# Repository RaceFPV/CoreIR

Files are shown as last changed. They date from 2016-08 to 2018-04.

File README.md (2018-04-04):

**What is this?**

CoreIR is an ultra low cost IR timing gate transponder compatible with i-lap rc timing gates. Usually this type of timing system is used for RC car or drone racing to track how fast you can run laps around a track. Using cheap and easy to find hardware, we've seen builds as cheap as $3 per transponder!

*[Now with a detailed build guide!](http://mrickert.com/2016/10/12/building-your-own-coreir-transponder/)*

**What's inside?**

CoreIR comes ready for you to input any 7 digit transponder ID you'd like, just edit the main arduino file's tx_id (CoreIR.ino) to set which transponder ID you would like to have. We have tested with a range from 1111111 to 9999999, but please be aware some id numbers seem to read/perform better than others!

*Don't want to edit arduino files? Use the new [CoreIR-Uplink desktop app!](https://github.com/slacker87/CoreIR-Uplink)*

**Required parts:**
* Arduino pro mini or pro micro (pro micro preferred)
* 9.1 ohm resistor
* npn transistor (2N222 preferred)
* IR led (TSAL6400 preferred)
* Arduino IDE 1.8.3 or higher

**Testing:**

You should see the following once you have built your tranceiver to confirm the code/hardware is working properly...
* Once the firmware is flashed, the led on the arduino should blink two times per second
* If the arduino is blinking around 2x per second, then the code is running correctly
* If the arduino is not blinking, or is blinking seemingly at random, the code needs to be reflashed as the upload failed (or there's a hardware issue)
* With the arduino blinking, point your phone camera at the IR led, the led should be emitting a purple hue
* If you see the purple color from the led on your phone camera, congratulations! Everthing is running smoothly.
* If you do not see any purple hue, but the arduino is blinking steadily, there is a hardware wiring issue or the led has been damaged, check your wiring.

**Wiring:**

##### For micro and pro micro boards:

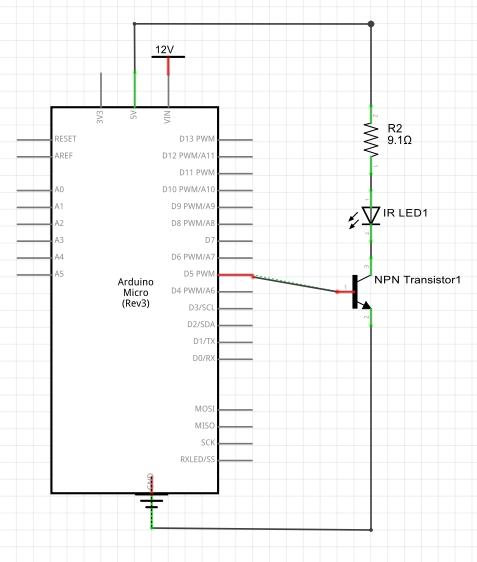
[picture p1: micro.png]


##### For nano and pro mini boards:

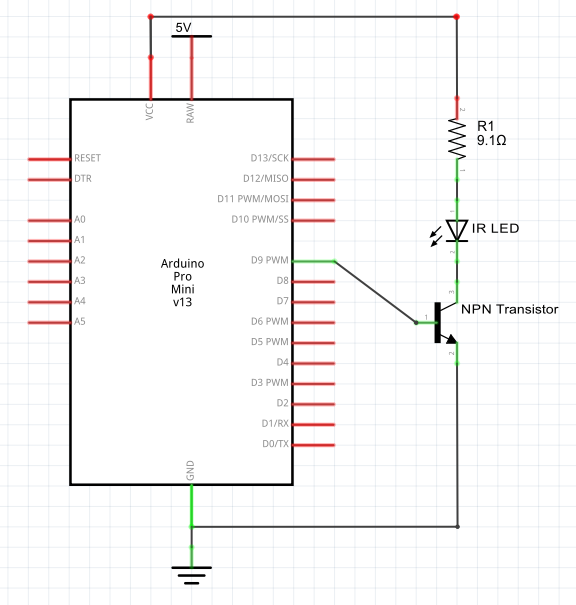
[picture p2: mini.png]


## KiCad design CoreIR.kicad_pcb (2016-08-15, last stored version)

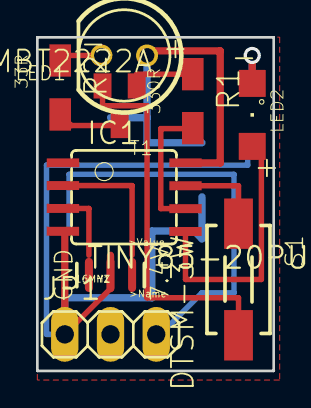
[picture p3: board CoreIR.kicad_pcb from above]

Board: 2 copper layers, 13.1 x 18.5 mm, 13 parts (0 on the bottom side), 12 nets.

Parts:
C1, C2: 10uF; C1206K
IC1: TINY85-20PU; 8S2
IC2: LD117AS50TR; SOT223
JP1: 1X03
LED1: LED5MM
LED2: SML1206
R1: 330R; R1206W
R2: 33R; R1206W
R3: 100R; R1206W
S1: DTSM-3W
T1: MMBT2222A; SOT23-BEC
Y1: 16MHZ; RESONATOR-SMD

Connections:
5V: C2.1, IC1.8, IC2.4, LED1.A
GND: C1.2, C2.2, IC1.4, IC2.1, JP1.1, R3.2, S1.2, T1.E, Y1.2
unnamed: IC1.5, LED2.A
unnamed: LED1.K, R2.1
unnamed: R2.2, T1.C
unnamed: R1.1, T1.B
unnamed: IC1.6, R1.2
unnamed: LED2.C, R3.1
unnamed: IC1.7, S1.1
unnamed: IC1.3, Y1.3
unnamed: IC1.2, Y1.1
VCC: C1.1, IC2.3, JP1.3

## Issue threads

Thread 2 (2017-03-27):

Undetected passes

EdwardDimaguila, 2017-03-27:
Hi Micheal,

I recently built this project transponder based on atmega 328. however i often missed laps especially when flying at high speeds through the sensor gate.

I read your commits and seen several times that you've changed the int khz value and finally settled to 426, why is it so? AFAIK the TSOP7000 IR detector used in the ilaps sensor bridge calls for 455khz as per datasheet, Gareth and Mitch measured the original ilaps transponders to have around 460 khz carrier, could this be the cause of my missed laps?

slacker87, 2017-06-19:
Potentially, but I've found that even stock ilap transponders have missed laps in certain conditions. Those conditions are: high speed flying, full sun directly on receiver gate. The sun emits a high enough amount of IR light that it effectively 'blinders' the receiver gate from properly seeing the transponders emitted IR led. Also please make sure your using version 2.0 as a _lot_ of improvements to readout were done for that build. One final note is that I used a logic analyzer to check the output of the IR pulses hitting the led from the arduino and it matches up 1 to 1 with the original boards. The original leds were picked so that ilap could dump direct uart out onto the led but with a bit of software magic that can be 'simulated' with software so that a different ir led can be used (as in this case). Hope this helps my apologies for the late response!

isopix, 2023-01-21:
I do wonder which is better and would skip less laps:
 - I-Lap (CoreIR)
 - Robitronic/EasyLap (RiCino Next)

Hi,

Could you comment on difference between I-Lap and Robitronic(and EasyLap clone)?
Both use IR and both got reverse-engineered clones.

https://github.com/zelogik/RicinoNext
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

They also have Robitronic compatible transponder:
https://github.com/zelogik/RicinoNext/tree/main/Hardware/Emitter/irda_robi
https://github.com/zelogik/RicinoNext/tree/main/Software

Isn't Robitronic better than I-Lap?

I know there's also reverse-engineered AMBrc clone (called RCHourGlass), but it's probably overkill for 1:43 cars

Closed 2017-06-19.

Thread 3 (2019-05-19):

Doesn't work with my i-lap rc timing gate

timemaster5, 2019-05-19:
Hi, sorry for the possibly stupid question. I tried everything to get this project working but without success. Here are some photos of my i-Lap gate system, can anybody confirm that is the same one as you're using with these transponders?

I tried multiple Arduinos - Pro Micro 3.3V 8Mhz (32u4), Pro Mini 5v 16Mhz (328p), both without any sign of readings (no blinking RX led on the receiver, no logged IDs). Also tried multiple IR diodes, your recommended one too. Transmission is working I can see the IDs sent with IR receiver build on a Raspberry Pi (irw tool).

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

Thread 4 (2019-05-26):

IR LED Pin

Orange-Murker, 2019-05-26:
IR output pin for ATmega328 (Arduino Pro Micro) should be 3 as the code states instead of 9 on the schematics. I tested PIN 3 and it outputs the signal.
```
// Arduino Duemilanove, Diecimila, LilyPad, Mini, Fio, Nano, etc
// ATmega48, ATmega88, ATmega168, ATmega328
#else
  //#define IR_USE_TIMER1   // tx = pin 9
  #define IR_USE_TIMER2     // tx = pin 3

#endif
```

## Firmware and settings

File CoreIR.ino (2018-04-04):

/*
*
* I-lap "transponder" compatible IR transmitter for RC timing system
*
* Type in a 7-digit ID and an alternate ID into the define fields before compiling.
* Note that using non-random ID numbers will increase your chances of encountering 
* another unit using the same ID.
* 
* !!!!IDs with repeated numbers may not register every pass. For best results don't repeat the same digit multiple times in a row!!!!
* Test ID code with system before using, if possible.
* 
*/
//CONFIGURABLE SECTION - SET TRANSPONDER ID
//Change transponder ID # by setting a different transponder number for tx_id
//WARNING: IDs set by CoreIR-Uplink tool will override these numbers
const long tx_id = 5118895;
const long tx_alt_id = 8901234;
const int easylap_id = 2;

// Enable debug info on serial output
//#define debug

// EasyRaceLapTimer support ---- TESTING
//  #define easytimer

//check which arduino board we are using and build accordingly
#if defined(__AVR_ATtiny84__) || defined(__AVR_ATtiny167__) || defined(__AVR_ATtiny85__)
  //if using an attiny build with all defaults, don't define anything
#elif defined(__AVR_ATmega32U4__)
  //if using an arduino micro build with eeprom enabled and different LED pin
  #define atmega
  #define micro
#elif defined(__AVR_ATmega328p__) || defined(__AVR_ATmega64__) || defined(__AVR_ATmega128__) || defined(__AVR_ATmega328__) || defined(__AVR_ATmega168__)
  //if using an atmega328p or similar build with eeprom enabled
  #define atmega
#else
  //define nothing
#endif

#ifdef easytimer
  #include "Easytimer.h"
#endif

//TODO, set pins for attiny85 boards
#ifdef micro
  // Set up alternate ID jumper bridge, shift pins because micro is special and uses pin 5 for IR output
  #define bridgePinIn 14
  #define bridgePinOut 15
  // Change the status LED location to the proper pin for the atmega32U4
  const int ledPin = 17;
#else
  // Set up alternate ID jumper bridge using normal pins 5 and 6
  #define bridgePinIn 5
  #define bridgePinOut 6
  // Use the normal status LED
  const int ledPin = 13;
#endif

// Include eeprom library for usb connectivity and CoreIR-Uplink ID saving
#ifdef atmega
  #include <EEPROM.h>
  #include "saved.h"
#endif
String incomingString = "";   // for incoming serial data

// Include libraries for IR LED frequency, speed and encoding
#include "IRsnd.h"
#include "Encode.h"

// Initialize IR LED send code
IRsend irsend;

// Set up status LED
int ledState = LOW;
long interval = 0;
unsigned long previousMillis = 0; // Allow status LED to blink without sacraficing a timer

void setup() {
  #ifdef atmega
    // save the new transponder numbers in eeprom if they are not already there
    if (EEPROMReadlong(64) != tx_id) {
      long tx_id = EEPROMReadlong(64);
    }
    if (EEPROMReadlong(70) != easylap_id) {
      long tx_alt_id = EEPROMReadlong(70);
    }
  #endif

  // set up jumper bridge for alternate ID
  pinMode(bridgePinIn, INPUT);
  digitalWrite(bridgePinIn, HIGH);
  pinMode(bridgePinOut, OUTPUT);
  digitalWrite(bridgePinOut, LOW);

  #ifdef atmega
    Serial.begin(9600);
    #if defined(micro) & defined(debug)
      while (!Serial)
    #endif
  #endif

  // Generate timecode
  #ifdef debug
    Serial.print("Building code from: ");
  #endif
  #if defined(easytimer)
    geteasylapcode();
  #else 
    if (digitalRead(bridgePinIn)) {
      #ifdef debug
        Serial.println("Main ID:");
        Serial.println(tx_id);
      #endif
      interval = 200; // Blink LED faster for regular id by default
      makeOutputCode(tx_id); // use alternate ID if unbridged
    } else {
      #ifdef debug
        Serial.println("Alternate ID: ");
        Serial.println(tx_alt_id);
      #endif
      interval = 1000; // Blink LED slower for alt id
      makeOutputCode(tx_alt_id); // use standard ID otherwise
    }
  #endif
  
  // Set up for blinking the status LED
  pinMode(ledPin, OUTPUT);
}

void loop() {
  #ifdef atmega
  //serial data stuff for coreir-uplink support
  // send data only when you receive data:
  #ifdef easytimer
    if (Serial.available() > 0) {
      // read the incoming byte:
      incomingString = Serial.readString();
      //if asked, send back the current ID
      if (incomingString == "readID") {
        Serial.println(EEPROMReadlong(70));
        incomingString = "";
      }
      else {
      //if asked, set a new ID
        incomingString.remove(0,7);
        long idtolong = incomingString.toInt();
        EEPROMWritelong(70, idtolong);
        delayMicroseconds(3000);
        long easylap_id = EEPROMReadlong(70);
        Serial.println(easylap_id);
        incomingString = "";
        }
      }
    #else
      if (Serial.available() > 0) {
      // read the incoming byte:
      incomingString = Serial.readString();
      //if asked, send back the current ID
      if (incomingString == "readID") {
        Serial.println(EEPROMReadlong(64));
        incomingString = "";
      }
      //if asked, set a new ID
      if (incomingString.length() > 7) {
        incomingString.remove(0,7);
        long idtolong = incomingString.toInt();
        EEPROMWritelong(64, idtolong);
        delayMicroseconds(3000);
        long tx_id = EEPROMReadlong(64);
        Serial.println(tx_id);
        incomingString = "";
        }
      }
    #endif
    #endif

    
  #ifdef easytimer
      irsend.sendRaw(buffer,NUM_BITS,38);
      delay(17 + random(0, 5));
   #else
      //Send the IR signal, then wait the appropriate amount of time before re-sending
      irsend.sendRaw(outputcode, codeLen, khz);
      delay(7 + random(2, 5));
    #endif
  
  // -----Status LED blink code start -----
    unsigned long currentMillis = millis();
    if (currentMillis - previousMillis >= interval) {
      // save the last time you blinked the LED
      previousMillis = currentMillis;
      // if the LED is off turn it on and vice-versa:
      if (ledState == LOW) {
        ledState = HIGH;
      } else {
        ledState = LOW;
      }
      // set the LED with the ledState of the variable:
      digitalWrite(ledPin, ledState);
    // -----LED blink code end -----
  }
  delayMicroseconds(500);
}

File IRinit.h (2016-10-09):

//******************************************************************************
// IRremote
// Origial code by Ken Shirriff
// Modified by Paul Stoffregen <paul@pjrc.com> to support other boards and timers
// Modified by Michael Rickert <Slacker87> for more accurate IR LED timings
// Interrupt code based on NECIRrcv by Joe Knapp
//******************************************************************************

#ifndef IRinit_h
#define IRinit_h

//------------------------------------------------------------------------------
// Include the right Arduino header
//
#if defined(ARDUINO) && (ARDUINO >= 100)
#  include <Arduino.h>
#else
# if !defined(IRPRONTO)
#   include <WProgram.h>
# endif
#endif

//------------------------------------------------------------------------------
// This handles definition and access to global variables
//
#ifdef IR_GLOBAL
# define EXTERN
#else
# define EXTERN extern
#endif

//------------------------------------------------------------------------------
// Information for the Interrupt Service Routine
//
#define RAWBUF  101  // Maximum length of raw duration buffer

typedef
  struct {
    // The fields are ordered to reduce memory over caused by struct-padding
    uint8_t       rcvstate;        // State Machine state
    uint8_t       blinkpin;
    uint8_t       blinkflag;       // true -> enable blinking of pin on IR processing
    uint8_t       rawlen;          // counter of entries in rawbuf
    unsigned int  timer;           // State timer, counts 50uS ticks.
    unsigned int  rawbuf[RAWBUF];  // raw data
    uint8_t       overflow;        // Raw buffer overflow occurred
  }
irparams_t;

// ISR State-Machine : Receiver States
#define STATE_IDLE      2
#define STATE_MARK      3
#define STATE_SPACE     4
#define STATE_STOP      5
#define STATE_OVERFLOW  6

// Allow all parts of the code access to the ISR data
// NB. The data can be changed by the ISR at any time, even mid-function
// Therefore we declare it as "volatile" to stop the compiler/CPU caching it
EXTERN  volatile irparams_t  irparams;

//------------------------------------------------------------------------------
// Defines for blinking the LED
//

#if defined(CORE_LED0_PIN)
  # define BLINKLED        CORE_LED0_PIN
  # define BLINKLED_ON()   (digitalWrite(CORE_LED0_PIN, HIGH))
  # define BLINKLED_OFF()  (digitalWrite(CORE_LED0_PIN, LOW))
#else
  # define BLINKLED        13
  # define BLINKLED_ON()  (PORTB |= B00100000)
  # define BLINKLED_OFF()  (PORTB &= B11011111)
#endif

//------------------------------------------------------------------------------
// CPU Frequency
//
// microseconds per clock interrupt tick
# define USECPERTICK 50

#ifdef F_CPU
  # define SYSCLOCK  F_CPU     // main Arduino clock
#else
  # define SYSCLOCK  16000000  // main Arduino clock
#endif

//------------------------------------------------------------------------------
// Defines for setting and clearing register bits
//
#ifndef cbi
  # define cbi(sfr, bit)  (_SFR_BYTE(sfr) &= ~_BV(bit))
#endif

#ifndef sbi
  # define sbi(sfr, bit)  (_SFR_BYTE(sfr) |= _BV(bit))
#endif

//------------------------------------------------------------------------------
// Define which timer to use
//

// Micro and Pro micro - ATmega32U4
#if defined(__AVR_ATmega32U4__)
  //#define IR_USE_TIMER1   // tx = pin 14
  #define IR_USE_TIMER3   // tx = pin 9

//MegaCore - ATmega64, ATmega128
#elif defined(__AVR_ATmega64__) || defined(__AVR_ATmega128__)
  #define IR_USE_TIMER1     // tx = pin 13

// MightyCore - ATmega8535, ATmega16, ATmega32
#elif defined(__AVR_ATmega8535__) || defined(__AVR_ATmega16__) || defined(__AVR_ATmega32__)
  #define IR_USE_TIMER1     // tx = pin 13

// Atmega8
#elif defined(__AVR_ATmega8__)
  #define IR_USE_TIMER1     // tx = pin 9

// ATtiny84
#elif defined(__AVR_ATtiny84__) || defined(__AVR_ATtiny167__)
  #define IR_USE_TIMER1     // tx = pin 6

//ATtiny85
#elif defined(__AVR_ATtiny85__)
  #define IR_USE_TIMER_TINY0   // tx = pin 1

// Arduino Duemilanove, Diecimila, LilyPad, Mini, Fio, Nano, etc
// ATmega48, ATmega88, ATmega168, ATmega328
#else
  //#define IR_USE_TIMER1   // tx = pin 9
  #define IR_USE_TIMER2     // tx = pin 3

#endif

//------------------------------------------------------------------------------
// Defines for Timer

//---------------------------------------------------------
// Timer2 (8 bits)
//
#if defined(IR_USE_TIMER2)

#define TIMER_RESET
#define TIMER_ENABLE_PWM    (TCCR2A |= _BV(COM2B1))
#define TIMER_DISABLE_PWM   (TCCR2A &= ~(_BV(COM2B1)))
#define TIMER_ENABLE_INTR   (TIMSK2 = _BV(OCIE2A))
#define TIMER_DISABLE_INTR  (TIMSK2 = 0)
#define TIMER_INTR_NAME     TIMER2_COMPA_vect

#define TIMER_CONFIG_KHZ(val) ({ \
  const uint8_t pwmval = SYSCLOCK / 2000 / (val); \
  TCCR2A               = _BV(WGM20); \
  TCCR2B               = _BV(WGM22) | _BV(CS20); \
  OCR2A                = pwmval; \
  OCR2B                = pwmval / 3; \
})

#define TIMER_COUNT_TOP  (SYSCLOCK * USECPERTICK / 1000000)

//-----------------
#if (TIMER_COUNT_TOP < 256)
# define TIMER_CONFIG_NORMAL() ({ \
    TCCR2A = _BV(WGM21); \
    TCCR2B = _BV(CS20); \
    OCR2A  = TIMER_COUNT_TOP; \
    TCNT2  = 0; \
  })
#else
# define TIMER_CONFIG_NORMAL() ({ \
    TCCR2A = _BV(WGM21); \
    TCCR2B = _BV(CS21); \
    OCR2A  = TIMER_COUNT_TOP / 8; \
    TCNT2  = 0; \
  })
#endif

//-----------------
#if defined(__AVR_ATmega1284__) || defined(__AVR_ATmega1284P__) \
|| defined(__AVR_ATmega644__) || defined(__AVR_ATmega644P__) \
|| defined(__AVR_ATmega324P__) || defined(__AVR_ATmega324A__) \
|| defined(__AVR_ATmega324PA__) || defined(__AVR_ATmega164A__) \
|| defined(__AVR_ATmega164P__)
# define TIMER_PWM_PIN  14             // MightyCore
#else
# define TIMER_PWM_PIN  3              // Arduino Duemilanove, Diecimila, LilyPad, etc
#endif               // ATmega48, ATmega88, ATmega168, ATmega328

//---------------------------------------------------------
// Timer1 (16 bits)
//
#elif defined(IR_USE_TIMER1)

#define TIMER_RESET
#define TIMER_ENABLE_PWM   (TCCR1A |= _BV(COM1A1))
#define TIMER_DISABLE_PWM  (TCCR1A &= ~(_BV(COM1A1)))

//-----------------
#if defined(__AVR_ATmega8__) || defined(__AVR_ATmega8535__) \
|| defined(__AVR_ATmega16__) || defined(__AVR_ATmega32__) \
|| defined(__AVR_ATmega64__) || defined(__AVR_ATmega128__)
# define TIMER_ENABLE_INTR   (TIMSK |= _BV(OCIE1A))
# define TIMER_DISABLE_INTR  (TIMSK &= ~_BV(OCIE1A))
#else
# define TIMER_ENABLE_INTR   (TIMSK1 = _BV(OCIE1A))
# define TIMER_DISABLE_INTR  (TIMSK1 = 0)
#endif

//-----------------
#define TIMER_INTR_NAME       TIMER1_COMPA_vect

#define TIMER_CONFIG_KHZ(val) ({ \
  const uint16_t pwmval = SYSCLOCK / 2000 / (val); \
  TCCR1A                = _BV(WGM11); \
  TCCR1B                = _BV(WGM13) | _BV(CS10); \
  ICR1                  = pwmval; \
  OCR1A                 = pwmval / 3; \
})

#define TIMER_CONFIG_NORMAL() ({ \
  TCCR1A = 0; \
  TCCR1B = _BV(WGM12) | _BV(CS10); \
  OCR1A  = SYSCLOCK * USECPERTICK / 1000000; \
  TCNT1  = 0; \
})
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

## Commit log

2016-05-10 Update schematic to reflect better signal distance
2016-05-11 Update schematic part numbers
2016-08-15 Remove full IRremote library and insert only required classes, also upload initial kicad drawings of attiny85 board
    [CoreIR.kicad_pcb, CoreIRv2.kicad_pcb]
2016-08-18 Add backwards compatibility for attiny devices without eeprom
2016-08-19 Fix for digispark pro
    [CoreIR.ino, IRinit.h]
2016-08-19 Implement reading from saved memory, flip defaults for pro micro
    [CoreIR.ino]
2016-08-22 Fix modulation/freq for arduino micro pro boards, flip it to pin 5, make it more accurate than previous iterations
    [CoreIR.ino, IRinit.h]
2016-08-22 Have code auto-detect the arduino board we are using and adjust accordingly (instead of previous manual settings)
2016-08-23 Use timer1 for atmega328p boards for better accuracy, also blink led different speed for alternate id
2016-08-24 Code cleanup, adjust location for reading bridgein pin
2016-08-24 Flip alt and regular id bridgepin output, clean up send timings so status LED does not fire at same time as IR LED
    [CoreIR.ino]
2016-08-24 Fix an edge case where ID may not get encoded, fix warning about invalid ID #s
    [CoreIR.ino]
2016-08-24 Discover a bitshift bug when generating transponder IDs, causing some IDs to work better than others. Merge IRrem into IRsnd, adjust timings
    [CoreIR.ino]
2016-08-24 Adjust frequency slightly, fix debug for atmega32u4 boards
    [CoreIR.ino]
2016-08-25 Tweak some more timings, fix outputcode array count
    [CoreIR.ino]
2016-08-27 Resolve an issue with pro micro boards and serial1 hanging
    [CoreIR.ino]
2016-08-29 Update schematic files, update hex files, remove old kicad drawings
    [CoreIR.kicad_pcb, CoreIRv2.kicad_pcb]
2016-09-02 Give props
2016-09-07 Fix a bug with new easylap compatibility stopping ilap sending
    [CoreIR.ino]
2016-09-28 Rework Board/CPU detection to try and better compile for attiny
    [CoreIR.ino]
2016-10-09 Revert "Clean up residule irremote receiver code bits"
    This reverts commit a6e66085ba5983dfa8338248b2632600e50a9f07.
    [CoreIR.ino, IRinit.h]
2016-10-09 Change khz rate, remove chips we'll never really use, remove timers never used, remove unused interrupt
2016-10-09 Always use 370khz and 24 frame, always use timer2 if avail
